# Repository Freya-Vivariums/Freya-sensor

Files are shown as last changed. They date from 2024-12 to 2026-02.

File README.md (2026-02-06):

Freya banner

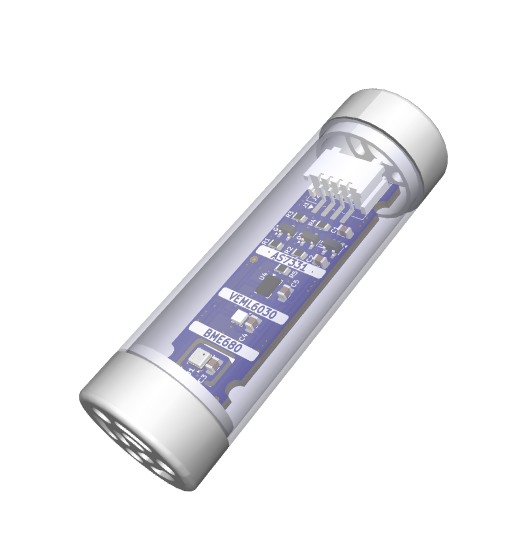
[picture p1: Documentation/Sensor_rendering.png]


The sensor is Freya's eyes and ears in the vivarium - the hardware that enables measurement of environmental conditions experienced by the inhabitants of the vivarium.

#### Measurement capabilities:
- Temperature
- Relative air humidity
- Barometric pressure
- Air quality (VOC)
- Ambient light (visible spectrum)
- UVA/UVB/UVC (spectral 220-400nm)

<br clear="right"/>

## Hardware
Designed with KiCad, the Freya Sensor is a curated collection of high-end integrated circuit sensors for comprehensive environmental monitoring in demanding conditions, with repairability and growth in mind.

#### Bosch BME680
I2C Address: **0x76**

Integrated environmental sensor combining temperature, humidity, barometric pressure, and VOC gas sensing for air quality monitoring. **[Datasheet](https://www.bosch-sensortec.com/media/boschsensortec/downloads/datasheets/bst-bme680-ds001.pdf)**

#### Vishay VEML6030
I2C Address: **0x10**

High-accuracy ambient light sensor with spectral response matching the human eye for precise lux measurement and photoperiod management. **[Datasheet](https://www.vishay.com/docs/84366/veml6030.pdf)**

#### ams OSRAM AS7331
I2C Address: **0x74** 

Three-channel spectral UV sensor with separated UVA, UVB, and UVC detection for UV bulb monitoring and safety verification. **[Datasheet](https://look.ams-osram.com/m/1856fd2c69c35605/original/AS7331-Spectral-UVA-B-C-Sensor.pdf)**

#### Power
The sensor module operates internally at 3.3V but accepts 5V input for improved noise immunity over longer cable runs. An on-board voltage regulator (**MIC5225-3.3YM5**) provides clean 3.3V power to all sensor ICs, while a bi-directional level shifter handles I²C communication between the 5V bus and 3.3V sensors.

> [!NOTE]  
> The PCB is finished with a coating for resisting the humid conditions.

## Enclosure

The electronics are housed in a protective enclosure designed in FreeCAD. The quart tube provides UV transparency for spectral measurements while mesh-filtered ventilation in the end caps enables air exchange for climate sensing. An internal holder positions the PCB and facilitates assembly.

## Software
The sensor driver is a TypeScript/Node.js application that runs as a systemd service on Linux/Debian systems. It provides sensor readings via D-Bus for integration with the Freya Vivarium Control System.

#### Installation
When installing the Freya system, the sensor driver is automatically installed. For manual installation:

```bash
wget -O install.sh https://github.com/Freya-Vivariums/Freya-terra-sensor/releases/latest/download/install.sh
chmod +x ./install.sh
sudo ./install.sh
```

The service runs automatically and can be monitored with:
```bash
systemctl status io.freya.EnvironmentSensorDriver.service
journalctl -u io.freya.EnvironmentSensorDriver.service -f
```

#### D-Bus Interface
Applications interact with the sensor via D-Bus on the system bus:
- **Service:** `io.freya.EnvironmentSensorDriver`
- **Path:** `/io/freya/EnvironmentSensorDriver`
- **Signals:** `measurement(variable: string, value: string)` - Emits readings for temperature, humidity, pressure, light, UVA, UVB, and UVC

## License & Collaboration
**Copyright© 2024-2026 Sanne 'SpuQ' Santens**. The hardware and enclosure are released under the [**CERN OHL-W**](Hardware/LICENSE.txt) license. The software is released under the [**GNU GPL-3.0**](Software/LICENSE.txt) license. [Trademark rules](https://github.com/Freya-Vivariums/.github/blob/main/brand/Freya_Trademark_Rules_and_Guidelines.md) apply to the Freya™ brand.

### Collaboration

If you'd like to contribute to this project, please follow these guidelines:
1. Fork the repository and create your branch from `main`.
2. Make your changes and ensure they adhere to the project's design style and conventions.
3. Test your changes thoroughly.
4. Ensure your commits are descriptive and well-documented.
5. Open a pull request, describing the changes you've made and the problem or feature they address.

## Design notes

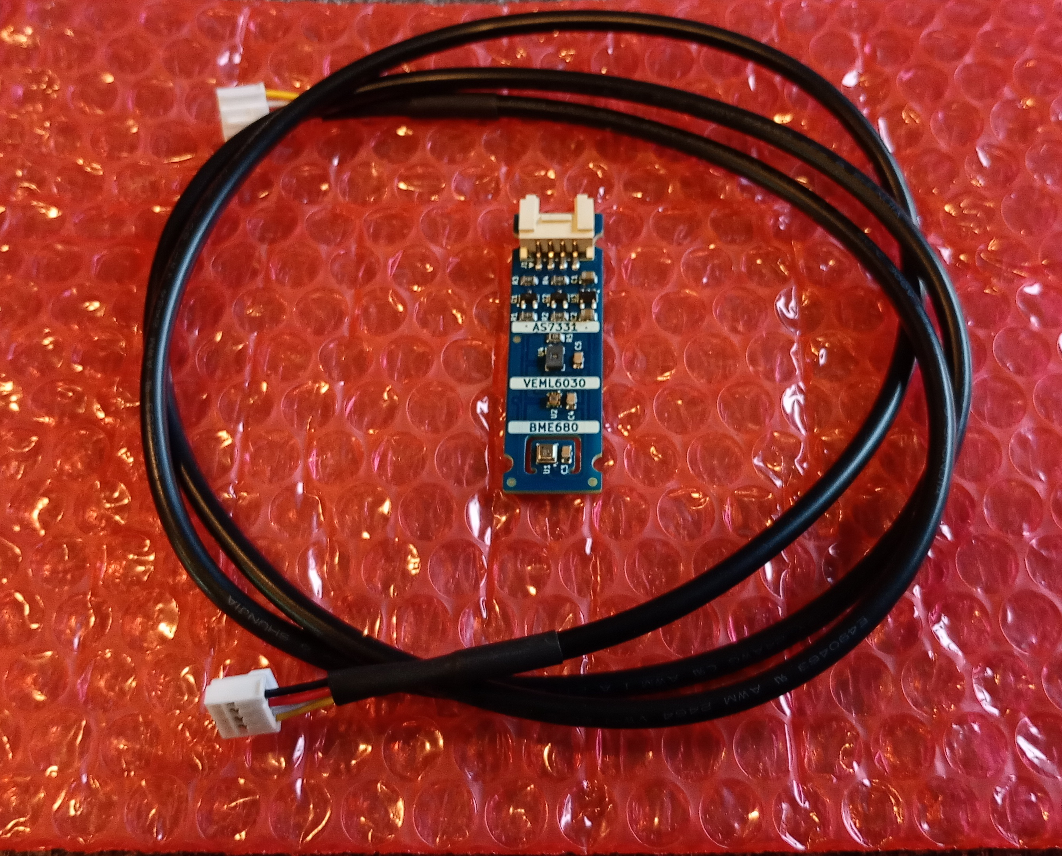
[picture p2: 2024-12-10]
Documentation/Freya_sensor.jpg

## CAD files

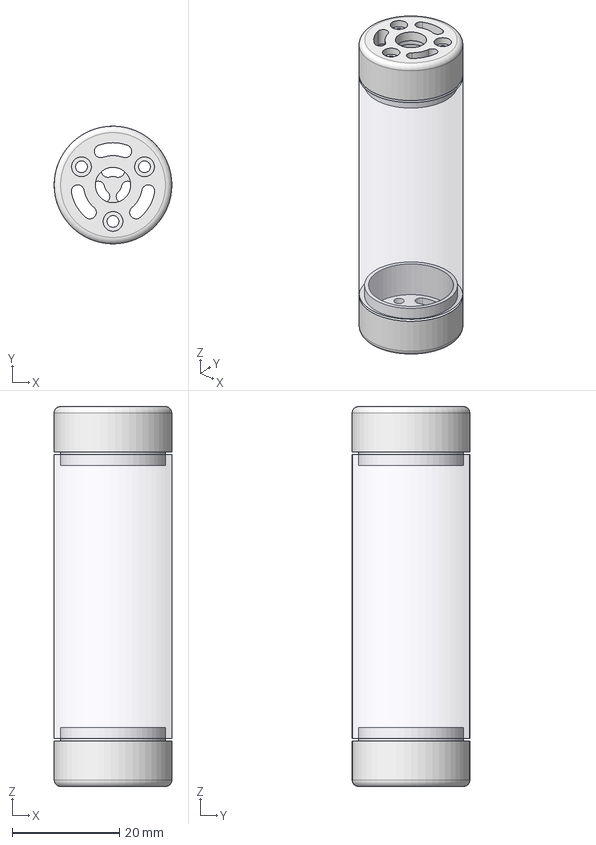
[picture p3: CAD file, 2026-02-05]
Enclosure/Enclosure.step
22.0 x 22.0 x 71.0 mm
EndCap_Bottom
EndCap_Top
QuartzTube

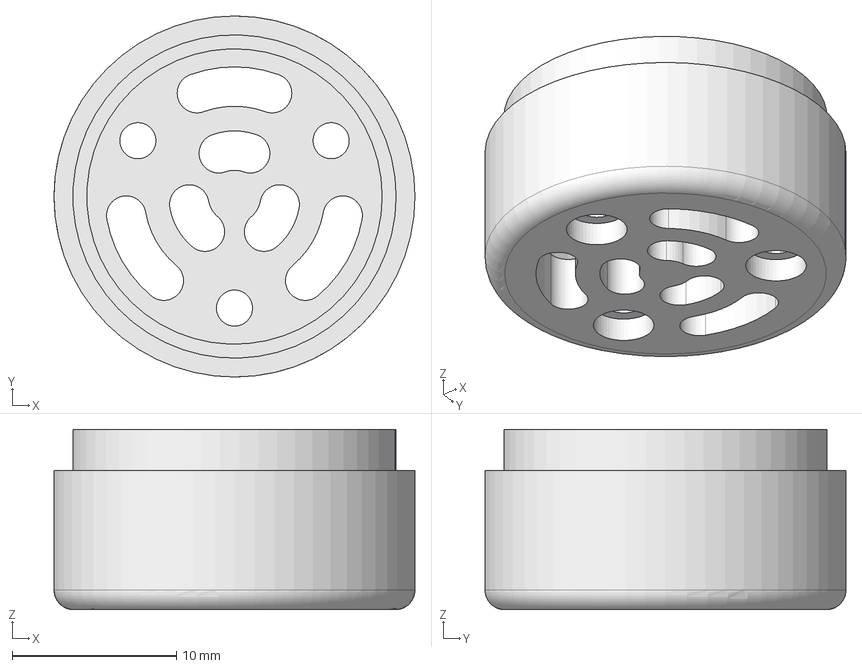
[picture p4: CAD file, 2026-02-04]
Enclosure/Enclosure-EndCap_Bottom.step
22.0 x 22.0 x 11.0 mm

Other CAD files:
Enclosure/Enclosure-EndCap_Top.step
Enclosure/Enclosure.FCStd

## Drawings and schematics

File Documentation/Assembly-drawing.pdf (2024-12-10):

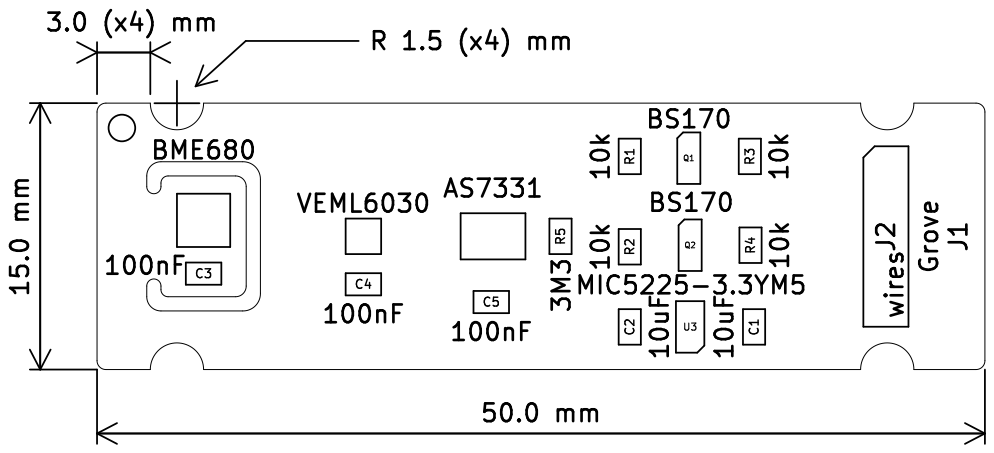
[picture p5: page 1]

Id: 1/1 Title: File: Freya-sensor.kicad_pcb Sheet:

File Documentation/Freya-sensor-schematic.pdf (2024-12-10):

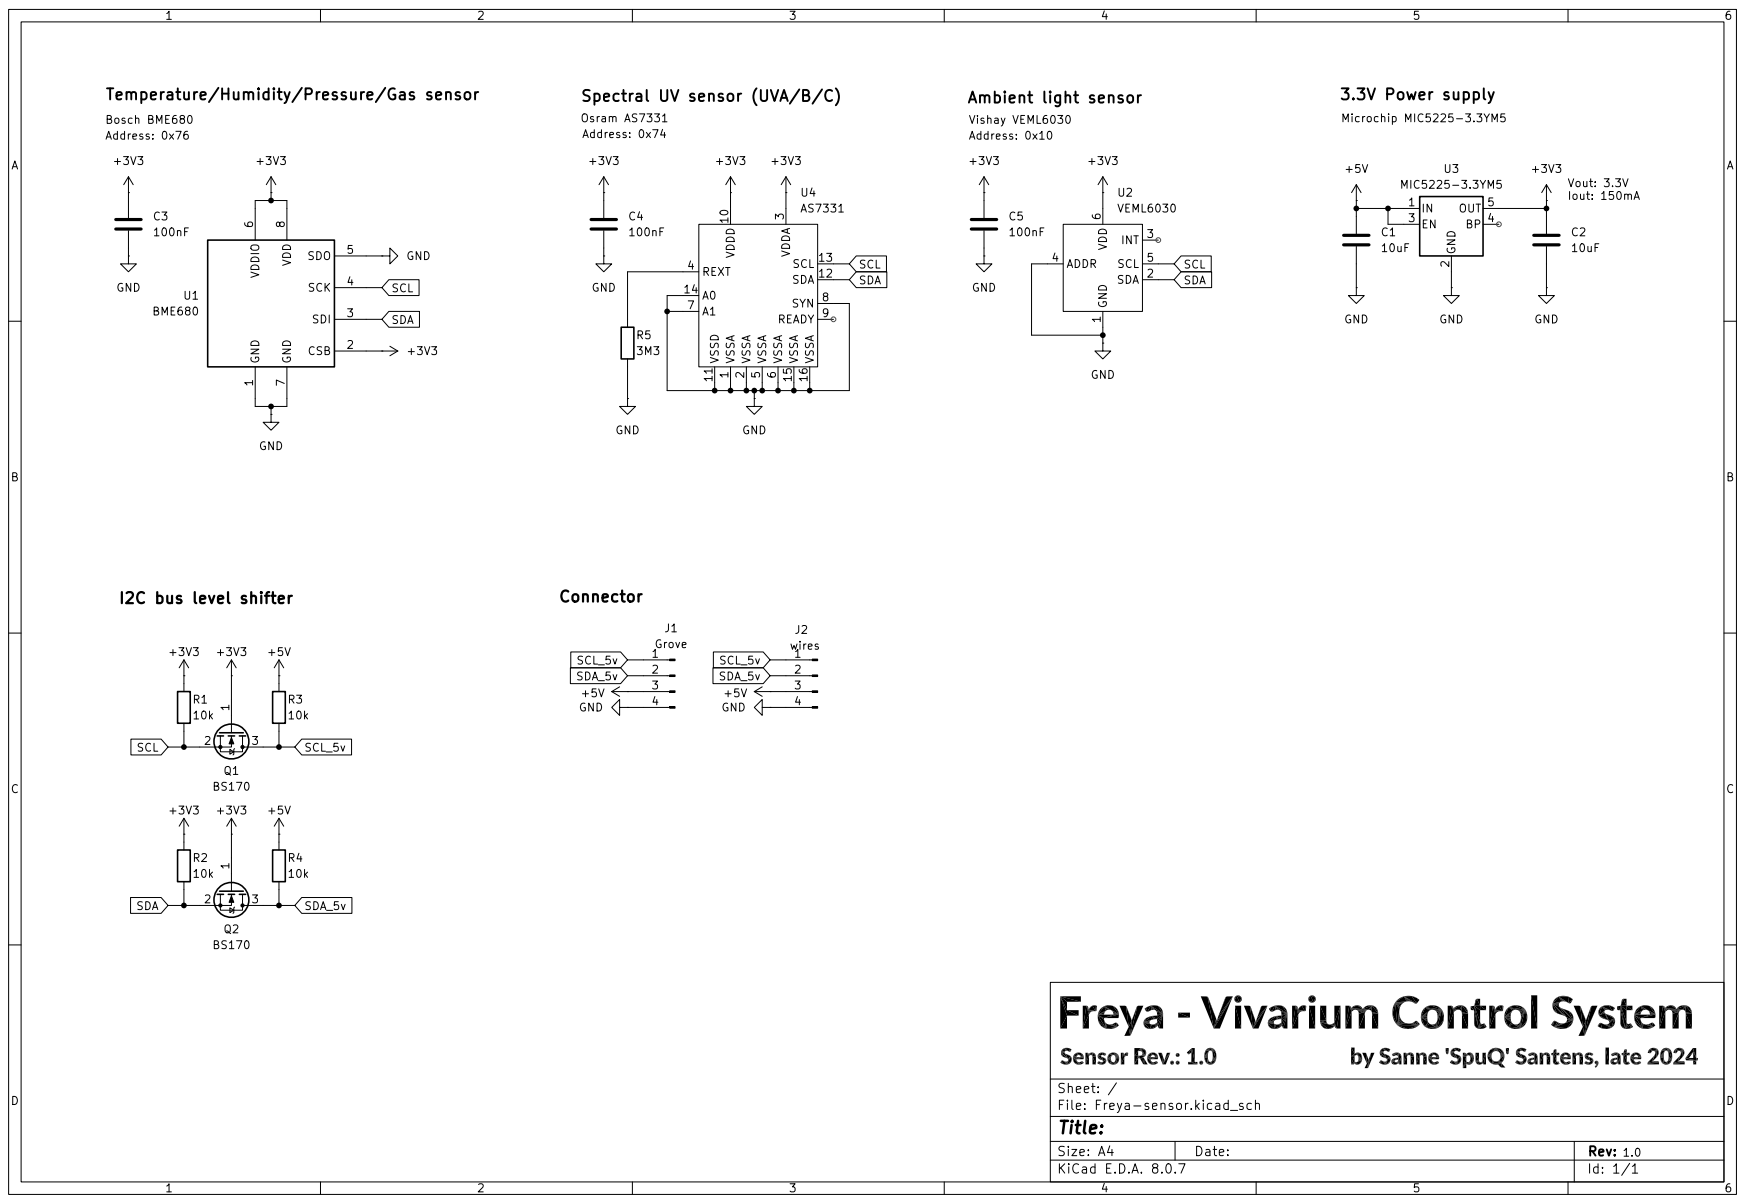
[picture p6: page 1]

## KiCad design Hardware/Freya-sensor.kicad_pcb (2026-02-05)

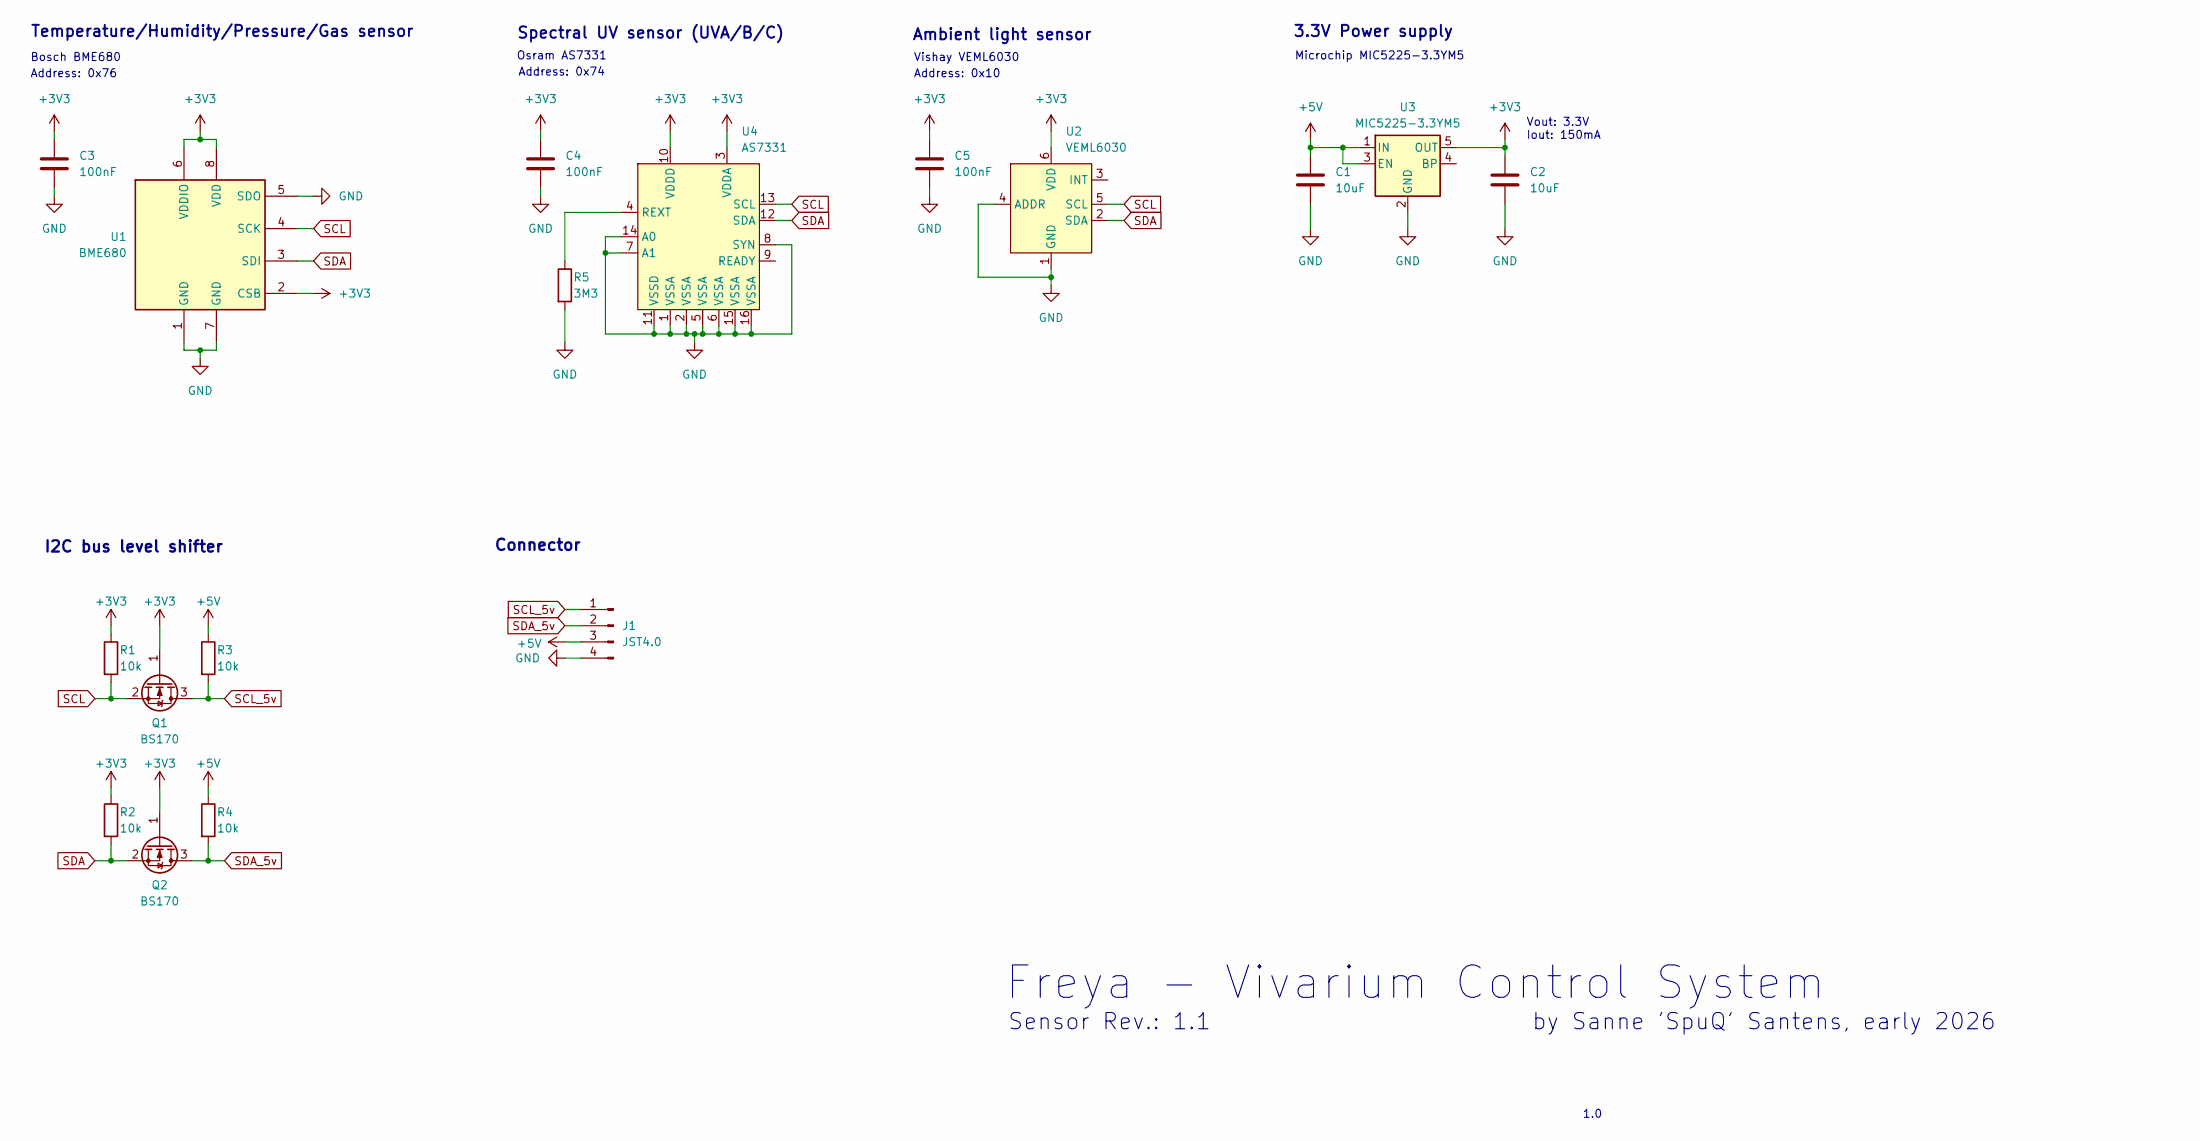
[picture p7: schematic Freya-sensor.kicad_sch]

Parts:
C1, C2: 10uF; C_0805_2012Metric
C3, C4, C5: 100nF; C_0805_2012Metric
J1: JST4.0; Grove_SMD_right_angle
Q1, Q2: BS170; SOT-23
R1, R2, R3, R4: 10k; R_0805_2012Metric
R5: 3M3; R_0805_2012Metric
U1: BME680
U2: VEML6030
U3: MIC5225-3.3YM5; SOT-23-5
U4: AS7331; Osram_AS7331

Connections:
+3V3: C2.1, C3.1, C4.1, C5.1, Q1.1 (G), Q2.1 (G), R1.1, R2.1, U1.2 (CSB), U1.6 (VDDIO), U1.8 (VDD), U2.6 (VDD), U3.5 (OUT), U4.3 (VDDA), U4.10 (VDDD)
+5V: C1.1, J1.3, R3.1, R4.1, U3.1 (IN), U3.3 (EN)
GND: C1.2, C2.2, C3.2, C4.2, C5.2, J1.4, J1.5, R5.2, U1.1 (GND), U1.5 (SDO), U1.7 (GND), U2.1 (GND), U2.4 (ADDR), U3.2 (GND), U4.1 (VSSA), U4.2 (VSSA), U4.5 (VSSA), U4.6 (VSSA), U4.7 (A1), U4.8 (SYN), U4.11 (VSSD), U4.14 (A0), U4.15 (VSSA), U4.16 (VSSA)
unnamed: R5.1, U4.4 (REXT)
SCL: Q1.2 (S), R1.2, U1.4 (SCK), U2.5 (SCL), U4.13 (SCL)
SCL_5v: J1.1, Q1.3 (D), R3.2
SDA: Q2.2 (S), R2.2, U1.3 (SDI), U2.2 (SDA), U4.12 (SDA)
SDA_5v: J1.2, Q2.3 (D), R4.2

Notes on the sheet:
Spectral UV sensor (UVA/B/C)
Bosch BME680
Sensor Rev.: 1.1 by Sanne 'SpuQ' Santens, early 2026
3.3V Power supply
Vout: 3.3V Iout: 150mA
Address: 0x76
Connector
Microchip MIC5225-3.3YM5
Address: 0x74
I2C bus level shifter
Vishay VEML6030
Osram AS7331
Address: 0x10
Ambient light sensor
Freya - Vivarium Control System
1.0
Temperature/Humidity/Pressure/Gas sensor

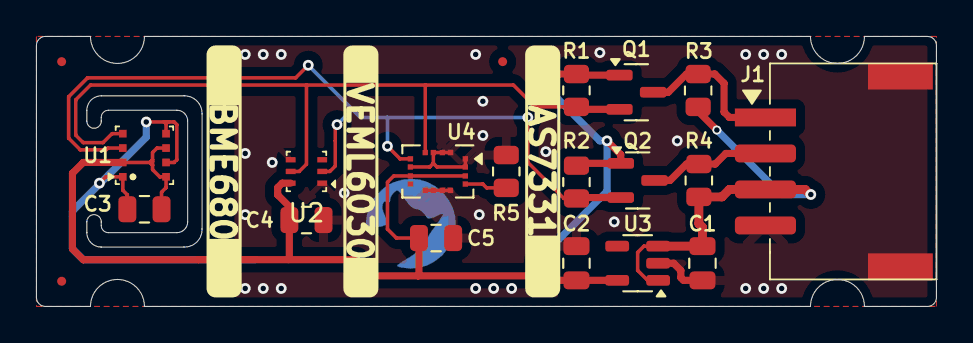
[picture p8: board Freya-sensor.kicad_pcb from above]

Board: 2 copper layers, 50.0 x 15.0 mm, 17 parts (0 on the bottom side), 8 nets.

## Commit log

2024-11-14 Initial commit v1
    [Freya-sensor.kicad_pcb, Freya-sensor.kicad_sch]
2024-12-10 Update documentation
    [Freya-sensor.kicad_pcb, Freya-sensor.kicad_sch]
2026-02-04 Enclosure in FreeCAD
    [Enclosure-EndCap_Bottom.step, Enclosure-EndCap_Top.step, Enclosure.FCStd]
2026-02-05 Rendering with enclosure
2026-02-05 ReadMe: Hardware + Enclosure concepts
2026-02-05 Enclosure 3D model
    [Enclosure.step, Freya-sensor.kicad_pcb]
2026-02-05 Cleanup PCB & schematic
    [Freya-sensor.kicad_pcb, Freya-sensor.kicad_sch]
2026-02-05 ReadMe: hardware: power circiut
2026-02-06 Monorepo structure
    [Freya-sensor.kicad_pcb, Freya-sensor.kicad_sch]
2026-02-06 ReadMe: Enclosure description
2026-02-09 Repo organization: software driver + client
2026-02-09 Fix AS7331 UV sensor driver: correct register map, OSR state machine, and irradiance conversion
    - Fixed register addresses: CREG1-3 at 0x02-0x04 (was 0x06-0x08)
    - Fixed OSR commands: proper config/measurement state transitions
    - Corrected CREG1 format: GAIN[7:4] | TIME[3:0] in single 8-bit register
    - Fixed measurement read: now correctly capturing UVA/UVB/UVC from right channels
    (previous code was reading TEMP as UVA, causing misalignment)
    - Added STATUS polling for data-ready flag instead of fixed delays
    - Implemented proper irradiance conversion: E = raw / (sensitivity × gain × tint_ms)
    - Verified with live sensor data: UVA ~6.6, UVB ~2.5, UVC ~0.5 µW/cm²
